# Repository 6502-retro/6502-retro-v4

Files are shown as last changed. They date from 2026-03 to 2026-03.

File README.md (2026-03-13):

# 6502-Retro! V4.4

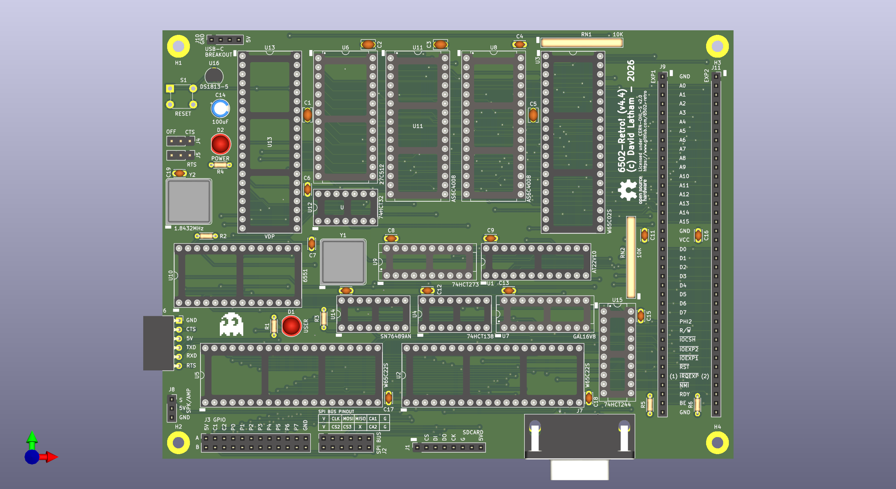
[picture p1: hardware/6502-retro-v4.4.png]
6502-Retro-V4.4


## ERRATA

See: [Errata](./ERRATA.md)

Continuing on from the 6502-Retro-V3-Banked SBC, this board now includes
additional IO in the form of a SPI bus carrying the SDCard interface and 2
additional SPI select lines.  There is also an additional 65C22 VIA with all of
its handshaking and port A and B pins brought out to a pin header.

Another optimization made relates to the RAM and ROM logic.  The RAM Bank is
controlled by the bottom 6 bits of the bank latch with the 7th bit used to
select between two rom banks and the 8th bit used to disable the ROM thus
enabling RAM in its place.

- Schematic: [6502-retro-v4.4.pdf](./hardware/6502-retro-v4.4.pdf)

## Memory

### Memory Bank Latch

Memory map is decoded with an ATF22V10 PLD.  Equations for which are found
here: [6502retrov4mem.pld](./pld/memdec/6502retrov4mem.pld)

- MSB of RAM BANK LATCH is ROMSW.
- PLD enables ROM (ROMEN=0) when ROMSW=0.
- PLD disables ROM(ROMEN=1) when ROMSW=1.
- RAM banks are driven by the lower 6bits giving 64 x 8k banks
- ROMSEL (bit 6) selects between the lower and upper 32k of ROM

### Memory Map

| Address | Description |
| --- | --- |
| 0x0000  | FIXED RAM START/ ZERO PAGE |
| 0x0100  | HW STACK |
| 0x0200  | FIXED USER RAM START |
| 0xBEFF  | FIXED USER RAM RAM END |
| 0xBF00  | IO- BANK LATCH (MSB=ROMSWITCH) (banks 0-63) |
| 0xBF10  | IO- ACIA/ UART |
| 0xBF20  | IO- VIA1 / SPI / Some IO |
| 0xBF30  | IO- VIA2 / Peripheral IO |
| 0xBF40  | IO- VDP/ TMS9918A Clone |
| 0xBF50  | IO- JSEN/ Joy Stick |
| 0xBF60  | IO- EXPANSION 1 |
| 0xBF70  | IO- EXPANSION 2 |
| 0xBF80- | IOCSH - On Expansion Bus |
| 0xBFF0  | |
| 0xC000  | HIGH/ BANKED RAM/ 64 x 8kb banks ram |
| 0xE000  | ROM/ 8KB ROM |
| 0xFFFA  | VECTORS/ HW vectors |
| 0xFFFF  | END OF ALL MEMORY |

## IRQ

There are 6 possible IRQ sources which are combined to a single /IRQ signal to
the CPU.  For convenience, a 16V8 GAL was used to perform this function.  The
equations for which are found here:
[6502-retro-v4-irq.pld](./pld/irq/6502-retro-v4-irq.pld)

This is not a priority encoder.

## License

Copyright © 2026 David Latham

This source describes hardware settled by the CERN-OHL-S v2. Licensed under the
CERN-OHL-S v2.0 or later. You may redistribute and modify this source and make
products using it under the terms of the CERN-OHL-S v2.0
[https://ohwr.org/cern_ohl_s_v2.txt](./LICENSE.md).

## Revision History

- v4.0 - Initial revision
- v4.1 - Fix SN76489 Audio Chip.  /SNWE must be driven by VIA, SNREADY requires
  2.2k pullup.
- v4.2 - Fix Power orientation on USB-C Adapter
- V4.3 - Larger board, memory decoder includes A7 address line, two expansion
  slots, pullups on expansion slot IRQ lines.

<!-- vim: set tw=80 cc=80: -->

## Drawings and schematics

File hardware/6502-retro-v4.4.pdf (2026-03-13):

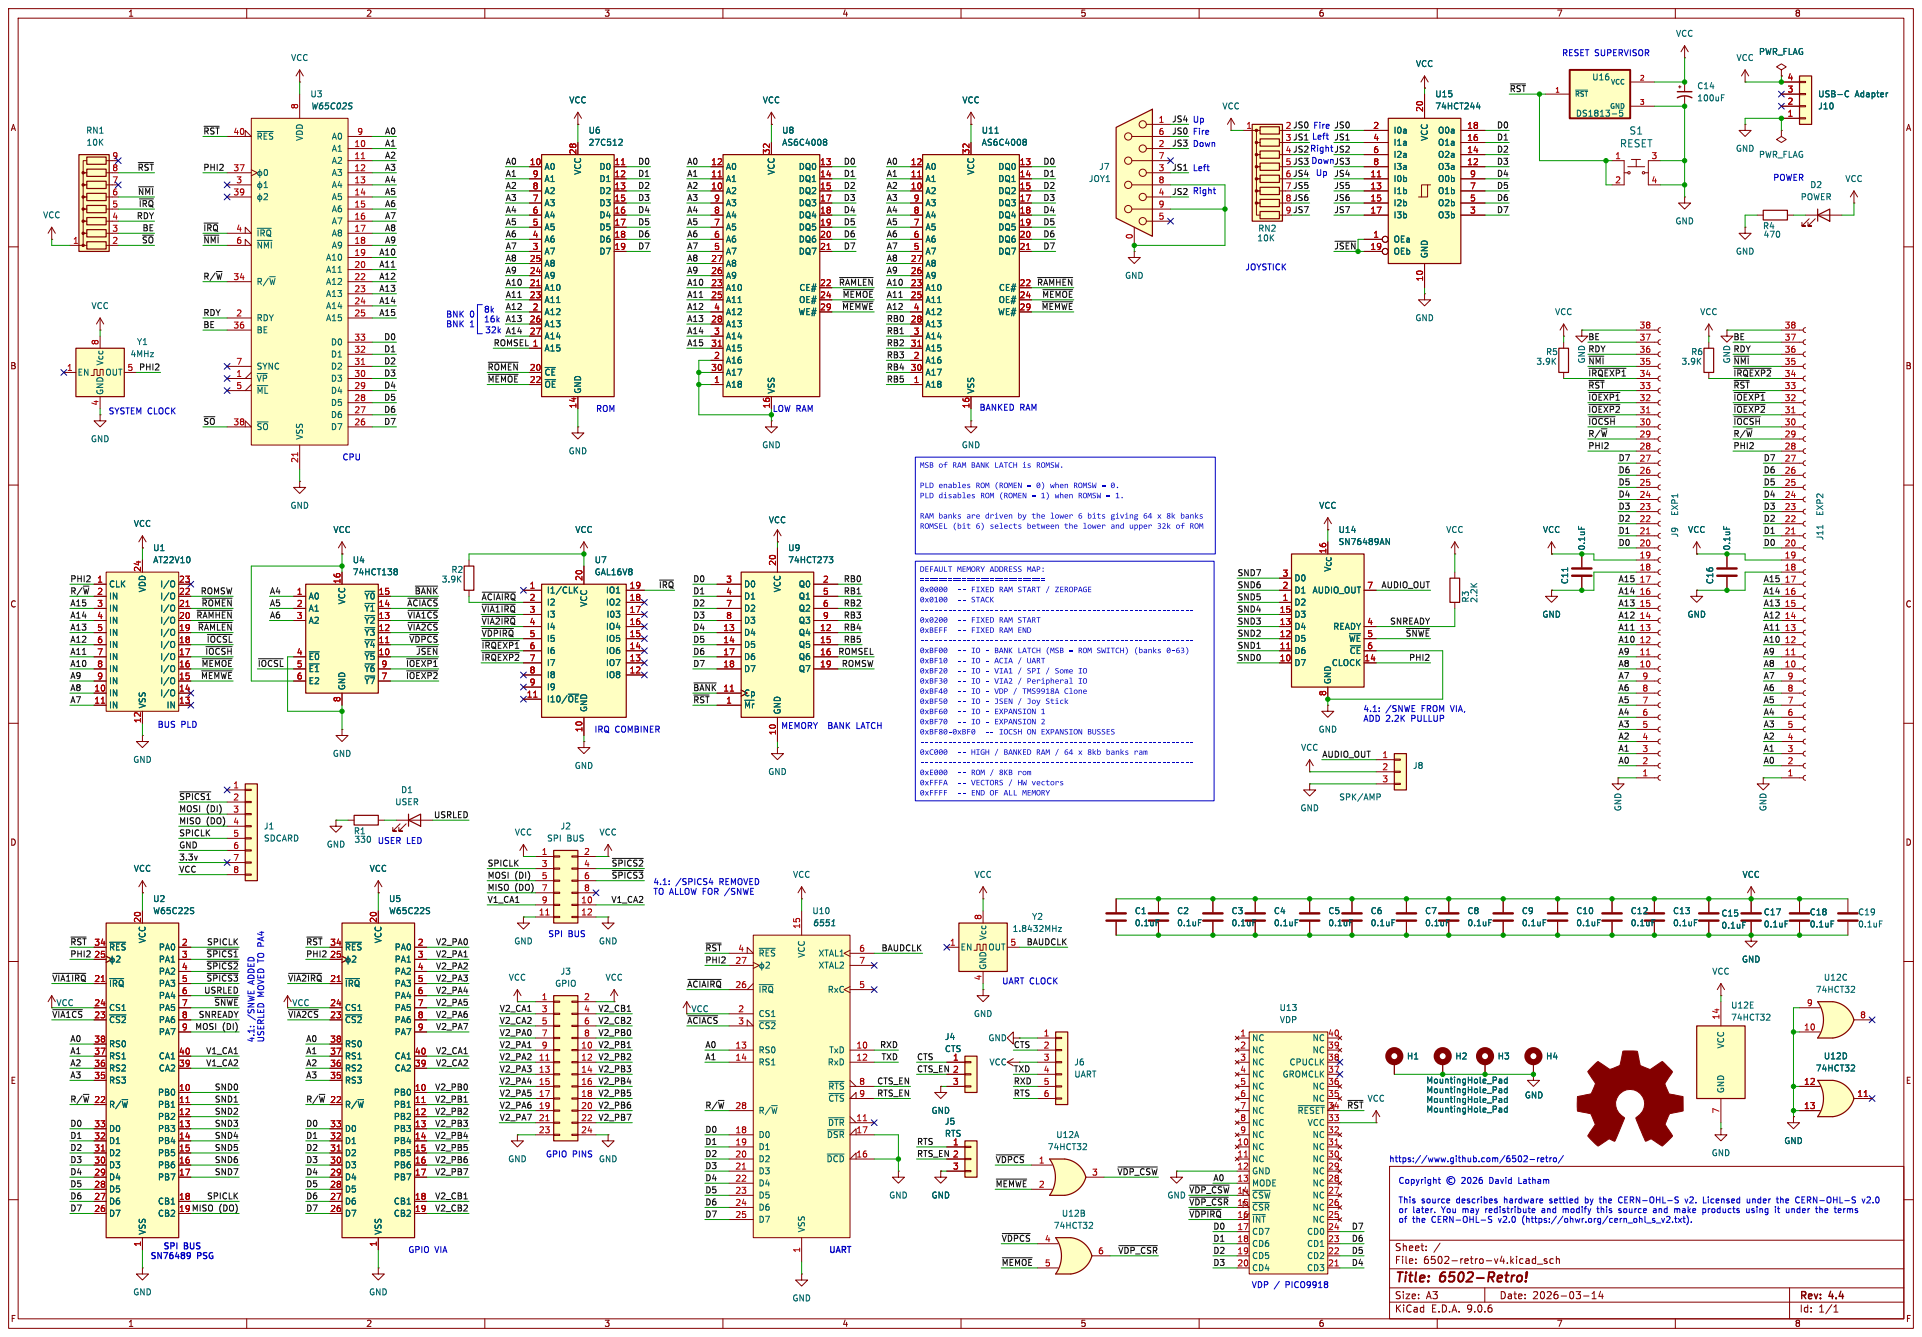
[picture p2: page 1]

8 AUDIO_OUT 7 READY 4 ~{WE}5 ~{CE}6 CLOCK 14 VCC C16 0.1uF VCC

0xFFFA -- VECTORS/ HWvectors 0xFFFF -- ENDOF ALL MEMORY MSBof RAMBANKLATCHis ROMSW. PLD enables ROM(ROMEN= 0) when ROMSW= 0. PLD disables ROM(ROMEN= 1) when ROMSW= 1. RAMbanks are driven by the lower 6 bits giving 64 x 8k banks ROMSEL(bit 6) selects between the lower and upper 32k of ROM

8 AUDIO_OUT 7 READY 4 ~{WE}5 ~{CE}6 CLOCK 14 U14 SN76489AN GND GND GND

0xBEFF -- FIXED RAMEND
----------------------------------------------------------- 0xBF00 -- IO - BANKLATCH(MSB = ROMSWITCH)(banks 0-63) 0xBF10 -- IO - ACIA / UART

0xBF20 -- IO - VIA1 / SPI / Some IO
0xBF40 -- IO - VDP/ TMS9918AClone
0xBF50 -- IO - JSEN / Joy Stick 0xBF60 -- IO - EXPANSION1

4.1: /SNWE FROM VIA, ADD 2.2K PULLUP

0xBF70 -- IO - EXPANSION2
0xBF80-0xBF0 -- IOCSHON EXPANSIONBUSSES
----------------------------------------------------------- 0xC000 -- HIGH / BANKEDRAM/ 64 x 8kb banks ram

1 XTAL1 6 XTAL2 7 RxC 5 TxD 10 RxD 12 ~{RTS} 8 ~{CTS} 9 ~{DTR}11 ~{DSR} 17 ~{DCD}16 U10

https://www.github.com/6502-retro/

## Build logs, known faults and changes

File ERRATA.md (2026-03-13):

# ERRATA

## V4.4

_None found yet. I have not had this version made yet._

## V4.3

Version of V4.3 of this board has some significant bugs as well as some lessor
but still concerning issues.

### BUGS (2026-03-03)

- Because the Atmel ATF22V10C outputs TTL logic levels, we need all the Logic
ICs to be TTL Level.  The LS variants are a bit too slow at 4MHz.  So HCT Logic
families are needed.
    - 74HCT273
    - 74HCT138
    - 74HCT244
    - 74HCT32

- Joystick Port is missing ground connections on pins 8 and 9.
- 74HCT244 has two enable pins (1 and 19) that need to be tied together and
linked to the Y5 on the 74HCT138 (U14)
- The SN76489A Data pins are connected to the VIA1-PORTB in the reverse order.
The code in tag v4.3 of the 6502-retro-boot and 6502-retro-os repos account for
this error by reversing the byte before sending to the chip.

### Concerning Issues

- There is significant noise on the audio.  A constant humming sound can be
heard.
- The IRQ processor when driven by the PICO9918 is set to also call an
interrupt service routine in the SN76489 library on the os which will turn off
the user LED when the counter reaches zero.
- The current limiting resistor on the RED Power LED is too low.  A stronger
470ohm or even 1k ohm is a better call.
- There is quite a significant ring on the phi2 signal.  Some form of signal
dampening should be applied to the clock signal.

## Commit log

2026-01-26 initial import
    [6502-retro-v4.kicad_sch]
2026-01-26 SN76489AN /SNWE signal needs to be driven by VIA
    [6502-retro-v4.kicad_sch]
2026-02-05 fix usb-c power pins
    [6502-retro-v4.kicad_sch]
2026-02-08 Schematic updated to v4.3
    - 2 bus expansion slots
    - larger board
    - GAL16v8 to OR together all IRQ
    [6502-retro-v4.kicad_sch]
2026-02-08 Add expansion bus pinout on silkscreen
2026-02-15 Add resistors to expansion slot IRQ pins
    [6502-retro-v4.kicad_sch]
2026-02-25 Fix silkscreen version 4.2 -> 4.3
2026-03-01 updated PLD equations to match whats on the board
2026-03-13 Revisions to correct bugs found in v4.3
    - Udd missing ground connections on Joystick port
    - Correct enable pins on 74HCT244
    - Relable support logic chips to HCT variants
    - Re-route data pins on SN76489A PSG
    - Change resistor value on power LED to 470ohm
    [6502-retro-v4.kicad_sch]
2026-03-13 fix silkscreen
